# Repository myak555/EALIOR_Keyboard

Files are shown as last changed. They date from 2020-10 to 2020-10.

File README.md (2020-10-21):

# EALIOR Keyboard
8-key chorded mechanical keyboard for tablets

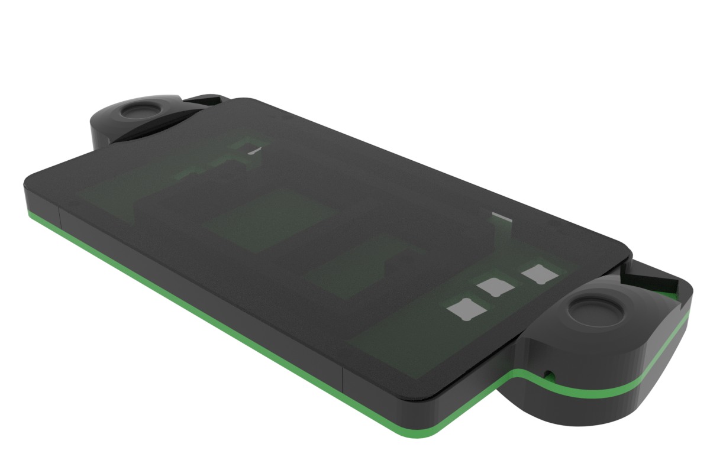
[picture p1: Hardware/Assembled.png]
Hardware


This is a much updated version of GKOS keyboard of Seppo Tiainen, 28-Mar-2010, and
GKOS keyboard of Pavel Travnik, 15-Sep-2019
  
Copyright (c) 2020 Mike Yakimov.

The name is derived from the first letters on the 6 chorded keys (if faced to the user):
  
Left_Thumb  E  I  Right_Thumb   
            A  O
            L  R

This is free software; you can redistribute it and/or modify it under the terms of the GNU Lesser General Public License as published by the Free Software Foundation; either version 3 of the License, or (at your option) any later version.

This software is distributed in the hope that it will be useful, but WITHOUT ANY WARRANTY; without even the implied warranty of MERCHANTABILITY or FITNESS FOR A PARTICULAR PURPOSE.  See the GNU Lesser General Public License for more details.

You should have received a copy of the GNU Lesser General Public License along with this library; if not, write to the Free Software Foundation, Inc., 51 Franklin St, Fifth Floor, Boston, MA  02110-1301  USA

 Inspired by prior work of:
 
* Seppo Tiainen (http://gkos.com/gkos/gkos-sixback.html)
* Pavel Travnik (https://hackaday.io/project/158377-mechanical-gkos-keyboard-for-phones-and-tablets) and the last but not least:
* Menny (https://github.com/AnySoftKeyboard/AnySoftKeyboard/commits?author=menny)

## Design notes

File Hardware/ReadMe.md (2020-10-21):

# Keyboard Hardware

The keyboard frame is composed of 4 laser-cut and 7 3D-printed parts. The actual sizes should be modified for the actual tablet. Instead of the laser, a CNC may be used (see NC files provided as an example). See Assembly.png.

1. Main keyboard frame - 3.4 mm plastic (Main_Frame.dxf)
1. Bottom cover - 3.4 mm plastic (Bottom_Cover.dxf)
1. Battery compartment cover - 3.4 mm plastic (Battery_Cover.dxf)
1. Top cover - 1.6 mm plastic (Top_Cover.dxf)
1. Upper left handle - PLA/ABS 3D print, 0.2 mm step(UpperLeft.stl)
1. Upper right handle - PLA/ABS 3D print, 0.2 mm step(UpperRight.stl)
1. Lower left handle - PLA/ABS 3D print, 0.2 mm step(BottomLeft.stl)
1. Lower right handle - PLA/ABS 3D print, 0.2 mm step(BottomRight.stl)
1. Horizontal extender, lower, - PLA/ABS 3D print, 0.2 mm step(MiddleBottom.stl)
1. Horizontal extender, upper, - PLA/ABS 3D print, 0.2 mm step(MiddleTop.stl)
1. Battery compartment - PLA/ABS 3D print, 0.2 mm step(BatteryBox3.stl)
1. Optional OTG pin holder - PLA/ABS 3D print, 0.2 mm step (OTG_Connector.stl)

# Bill of materials

See Schematics.png for assebly.

1. Sparkfun Arduino Micro Pro or equivalent - 1 ea
1. Micro-USB male connectors - 2 ea
1. Cherry mechanical switches or equivalents - 8 ea
1. 3 mm boxy LEDs (to fit Cherry LED openings) - 2 ea
1. Resistors 1.1K - 2 ea 
1. Power switch, 2 contact pairs  - 1 ea
1. Reset pushbutton - 1 ea
1. (Optional) perfboard - 1 ea
1. (Optional) pins, male 1x4 - 1 ea

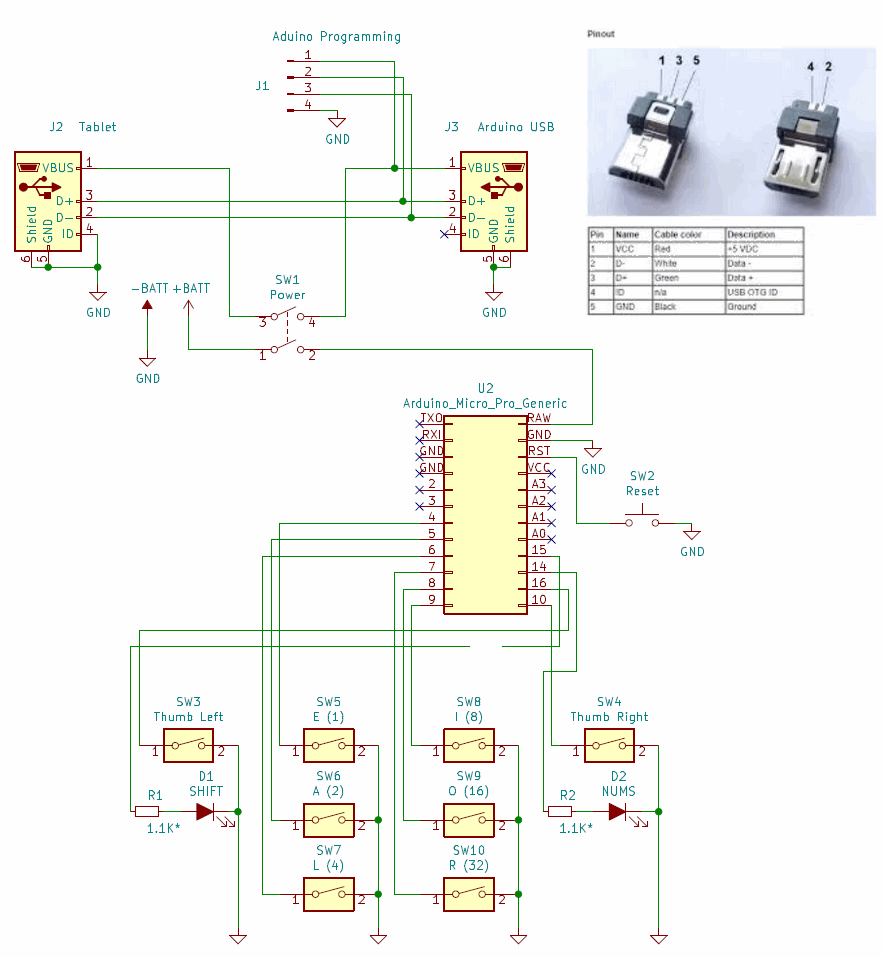
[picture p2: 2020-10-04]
Hardware/Schematics.png

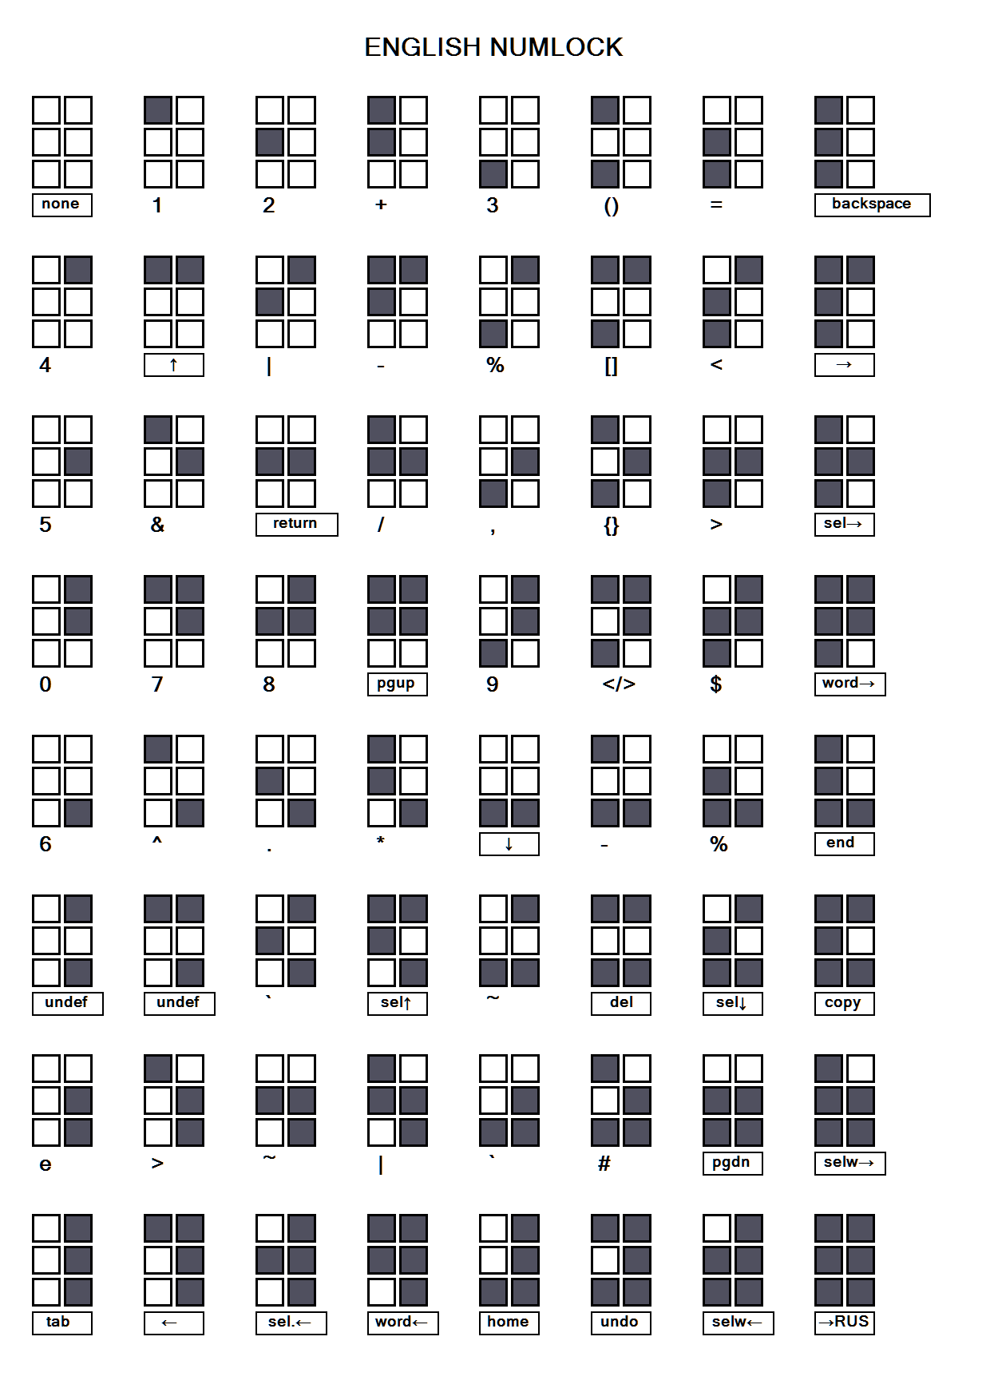
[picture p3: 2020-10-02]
Layout_Russian_Standard/ENGLISH_NUMLOCK_Layout_Russian_Standard.png

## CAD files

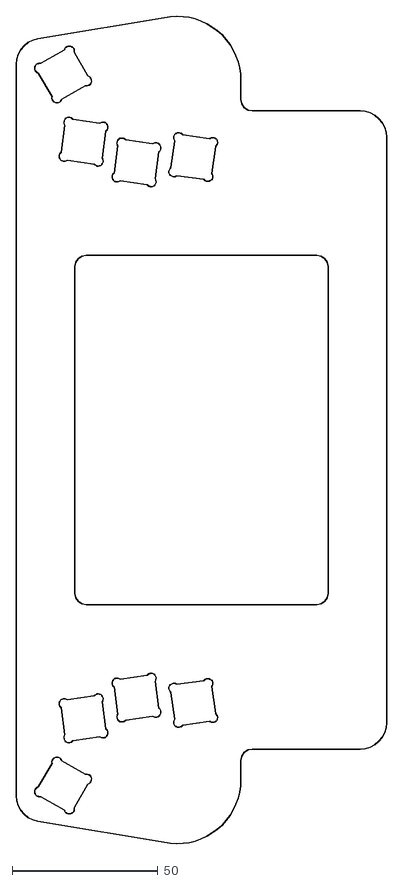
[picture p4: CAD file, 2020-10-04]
Hardware/Main_Frame.dxf
127.0 x 284.0

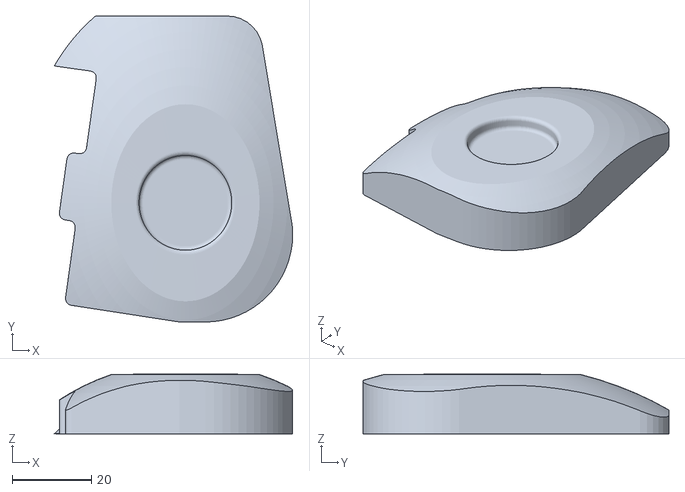
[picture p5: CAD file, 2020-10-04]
Hardware/BottomLeft.stl
60.0 x 77.0 x 15.0

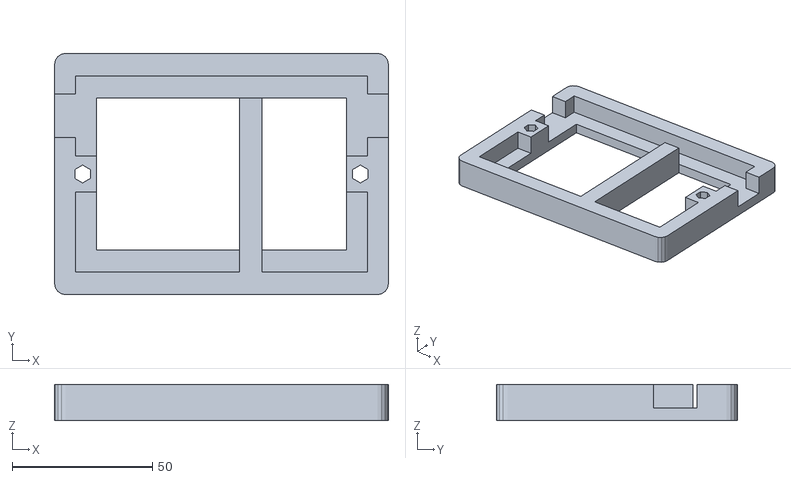
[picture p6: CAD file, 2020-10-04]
Hardware/BattryBox3.stl
119.0 x 86.0 x 13.0

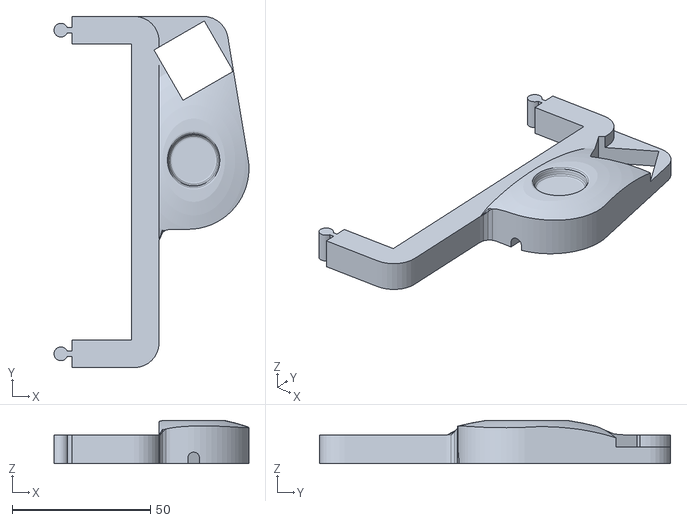
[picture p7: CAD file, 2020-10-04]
Hardware/UpperRight.stl
70.5 x 127.0 x 15.7

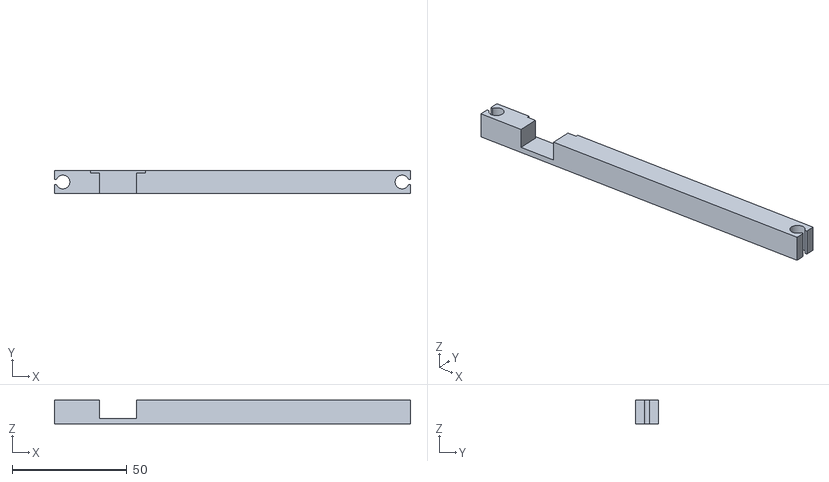
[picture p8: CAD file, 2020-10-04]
Hardware/MiddleTop.stl
155.4 x 10.0 x 10.3

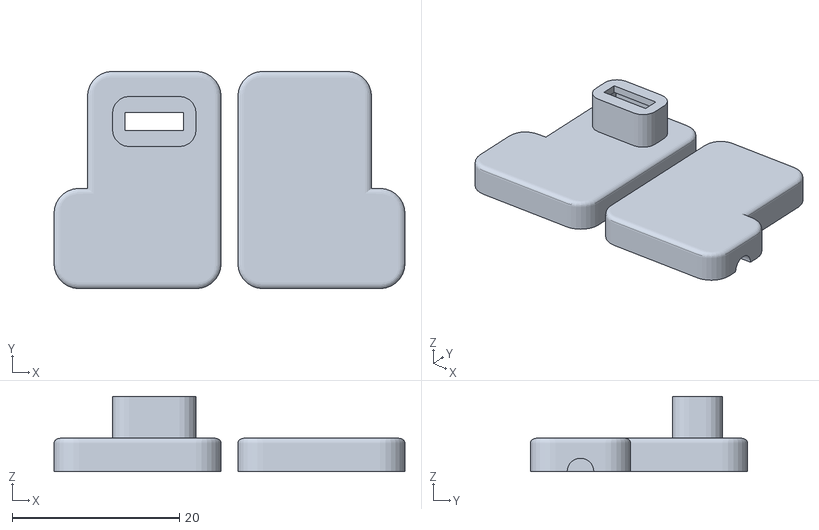
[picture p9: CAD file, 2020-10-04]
Hardware/OTG_Connector.stl
42.0 x 26.0 x 9.00

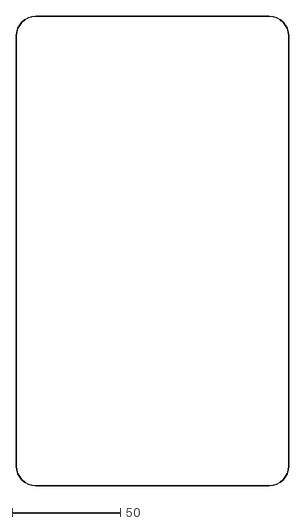
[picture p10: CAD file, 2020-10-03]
Hardware/Top_Cover.dxf
126.0 x 217.0

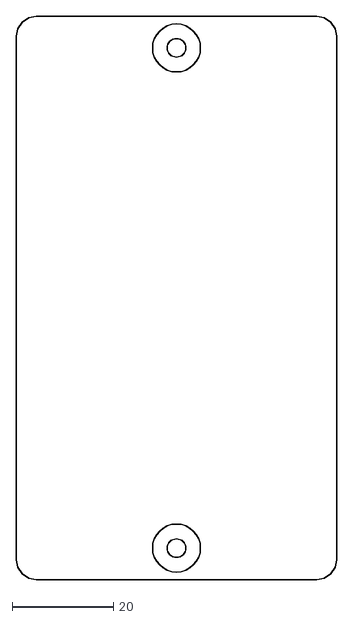
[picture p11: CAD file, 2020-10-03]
Hardware/Battery_Cover.dxf
63.5 x 111.6

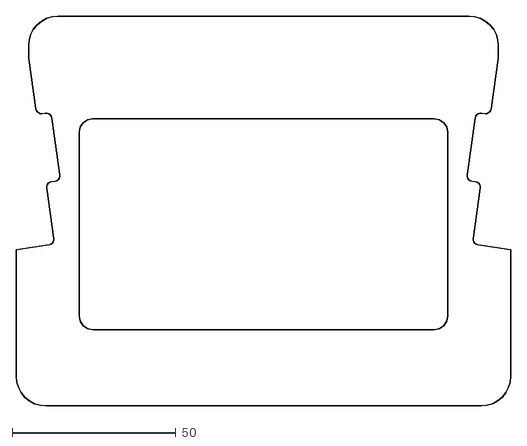
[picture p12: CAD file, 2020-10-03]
Hardware/Bottom_Cover.dxf
151.0 x 119.0

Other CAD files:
Hardware/BottomRight.stl
Hardware/UpperLeft.stl
Hardware/MiddleBottom.stl

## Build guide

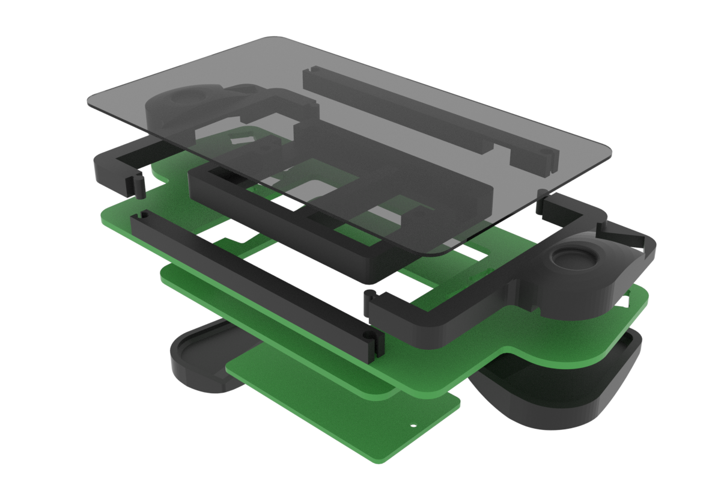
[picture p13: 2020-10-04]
Hardware/Assembly.png

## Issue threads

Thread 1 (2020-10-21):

With AnySoftKeyboard, shift is inconsistent with Russian layout

myak555, 2020-10-21:
Pressing Shift-Arrow on a hardware keyboard selects text. After the Shift is released and any button is pressed, AnySoftKeyboard believes that Shift is still pressed.

The issue is not observed in the the English layout.

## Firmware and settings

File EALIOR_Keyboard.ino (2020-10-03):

/*
  EALIOR (mark 4)
  This is a much updated version of GKOS keyboard of Seppo Tiainen, 28-Mar-2010, and
  GKOS keyboard of Pavel Travnik, 15-Sep-2019
  Copyright (c) 2020 Mike Yakimov.  All rights reserved.

  The name is derived from the first letters on the 6 chorded keys (if faced to the user):
  Left_Thumb  E  I  Right_Thumb   
              A  O
              L  R

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
 Inspired by work of: 
    Seppo Tiainen (http://gkos.com/gkos/gkos-sixback.html)
    Pavel Travnik (https://hackaday.io/project/158377-mechanical-gkos-keyboard-for-phones-and-tablets)
    and the last but not least: Menny (https://github.com/AnySoftKeyboard/AnySoftKeyboard/commits?author=menny)
*/

////////////////////////////////////////////////////////
//
// This code implementation is for (Chinese clone) Sparkfun Micro Pro ATMmega32U4 5V
//
// Pin assignment:
// Keys:
// Left_Thumb  E  I  Right_Thumb   
// Left_LED    A  O  Right_LED
//             L  R
//    16       5  8       10 
//    15       6  9       14
//             7  10
//
////////////////////////////////////////////////////////


#include "EALIOR_Decoder.hpp"

// Uncomment for serial debugging
//#define _DEBUG

static EALIOR_Hardware hardware;
static EALIOR_Decoder decoder;

//
// Setup code here, to run once:
//
void setup()
{
  #ifdef _DEBUG
  Serial.begin(9600);
  #endif
  hardware.init();
  decoder.init( &hardware);
}

//
// Runs continuously
//
void loop()
{
  if (hardware.readButtons())
    decoder.processKey();
  #ifdef _DEBUG
  delay(100);
  #else
  hardware.checkSleepRequired();
  #endif
}

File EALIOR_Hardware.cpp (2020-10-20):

/////////////////////////////////////////////////////////
//
//  EALIOR - 8-key chorded keyboard for tablets
//  Copyright (c) 2020 Mike Yakimov.  All rights reserved.
//  See main file for the license
//
//////////////////////////////////////////////////////////

#include <Arduino.h>
#include <Keyboard.h>
#include <LowPower.h>
#include "characters.h"
#include "EALIOR_Hardware.hpp"

// Uncomment to disable features while debugging
//#define _DISABLE_KEYBOARD
//#define _DISABLE_POWERSAVE
//#define _DEBUG

void EALIOR_Hardware::init(){
  pinMode(_LED_LEFT_, OUTPUT);
  pinMode(_LED_RIGHT_, OUTPUT);
  _writeLEDs( true, true);
  _kbdActive = false;
  for ( int i = 0; i < 8; i++){
    pinMode(_EALIORPins[i], INPUT_PULLUP);
    _kbdActive = _kbdActive || _readPinBool(i);
  }
  _kbdActive = !_kbdActive; // if any key is stuck, no runover
  if ( !_kbdActive) return;
  #ifndef _DISABLE_KEYBOARD
  Keyboard.begin();
  #endif
  _blinkLEDs();
  _setLEDs();
  _lastCommandReceived = millis();
}

//
// Reads the rear 6 buttons, processes them into the press codes
//
bool EALIOR_Hardware::readButtons(){
  if( !_kbdActive) return false;
  _readModeButtons();
  uint8_t button_weight = 1;
  int pin = 0;

  // Return empty immediately if 10 ms not elapsed
  _time = millis();
  if ((_time - _previousTime) < (10 + 64 * _autoRepeat)) return false;

  // Read buttons and form a code 
  _presentChord = 0;
  for( int i=0; i<6; i++){
    pin = _readPin( i);
    _presentChord += pin * button_weight;
    button_weight += button_weight; 
  }
  if(_presentChord) _lastCommandReceived = millis();
  #ifdef _DEBUG
  if(_presentChord)
    Serial.println( _presentChord, DEC);
  #endif

  // any buttons pressed
  if (_presentChord != 0){
    // Chord pressed long enough for autorepeat
    _autoCounter++;
    if (_autoCounter >= 100){
      _autoCounter = 99;
      _autoRepeat = 1;
    }

    // Chord pressed long enough to be first chord in Chordon
    //_firstCounter++;
    //if (_firstCounter > 25){
    //  _firstCounter = 25;
    //  if (_firstChord == 0) _firstChord = _presentChord;
    //}
  }

  // New key(s) pressed, expect a new character soon
  if (_presentChord > _previousChord){
    _gNew = true;
    _autoCounter = 0;
    _autoRepeat = 0;
    //_firstCounter = 0;
  }

  // key(s) relased
  if (_presentChord < _previousChord){
    _autoCounter = 0;
    _autoRepeat = 0;
    //EALIOR_firstCounter = 0;
    _gChord = _previousChord;  // the chord before the first release of key(s) is what we are after
    _previousChord = _presentChord;  
    _previousTime = _time;
    if (!_gNew) return false;
    _gNew = false; // next key releases will no more represent chords for characters
    return true; // a real chord entered!
  }

  // no buttons pressed
  //if (_presentChord == 0)
  //{
  //  _firstChord = 0; 
  //  _firstCounter = 0;
  //}
  _previousChord = _presentChord; // to be able to compare next time
  _previousTime = _time;

  if (!_autoRepeat) return false;
  _gChord = _previousChord;
  //_firstCounter = 0;
  //_firstChord = 0;
  return true;
}

void EALIOR_Hardware::setMode( uint8_t mode){
  if( shiftMode == mode) return;
  shiftMode = mode;
  _setLEDs();
}

void EALIOR_Hardware::_setLEDs(){
  uint8_t tmp = shiftMode % 5;
  const bool leftLED[5] = {false, true, true, false, true};
  const bool rightLED[5] = {false, false, false, true, true};
  _writeLEDs( leftLED[tmp], rightLED[tmp]);
}

void EALIOR_Hardware::kbdPress(char key){
  #ifndef _DISABLE_KEYBOARD
  kbdEnable();
  Keyboard.press( key);
  #endif
}

void EALIOR_Hardware::kbdWrite(char key){
  #ifndef _DISABLE_KEYBOARD
  kbdEnable();
  Keyboard.write( key);
  #endif
}

void EALIOR_Hardware::kbdPrint(String s){
  #ifndef _DISABLE_KEYBOARD
  kbdEnable();
  Keyboard.print( s);
  #endif
}

void EALIOR_Hardware::kbdRelease(char key){
  #ifndef _DISABLE_KEYBOARD
  kbdEnable();
  Keyboard.release( key);
  #endif
}

void EALIOR_Hardware::kbdReleaseAll(){
  #ifndef _DISABLE_KEYBOARD
  kbdEnable();
  Keyboard.releaseAll();
  #endif
}
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

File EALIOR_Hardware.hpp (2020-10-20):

/////////////////////////////////////////////////////////
//
//  EALIOR - 8-key chorded keyboard for tablets
//  Copyright (c) 2020 Mike Yakimov.  All rights reserved.
//  See main file for the license
//
//////////////////////////////////////////////////////////

#ifndef _EALIOR_HARDWARE_HPP
#define _EALIOR_HARDWARE_HPP

// if the user forgets to switch off the keyboard, go to sleep to prevent the battery drain
// 180 seconds is the default
#define SLEEP_DELAY (180000L)

// upon the keyboard connection, the system must recognize it
// tested on PC 1000 ms Ok
#define KBD_WAKEUP_TIMEOUT 1000

// double-pressing shift results in release capslock
#define DOUBLE_PRESS_TIMEOUT 300

// controls the wait upon a buttion press, e.g. after pressing Control or Shift
#define BUTTON_PRESS_TIMEOUT 30

//
// Pin assignment
//
#define _EALIOR_KEY_0_      4
#define _EALIOR_KEY_1_      5
#define _EALIOR_KEY_2_      6
#define _EALIOR_KEY_3_      7
#define _EALIOR_KEY_4_      8
#define _EALIOR_KEY_5_      9
#define _THUMB_KEY_LEFT_   16
#define _THUMB_KEY_RIGHT_  10
#define _LED_LEFT_         15
#define _LED_RIGHT_        14

class EALIOR_Hardware{
  public:
    void init();
    bool readButtons();
    void setMode( uint8_t mode);
    inline uint16_t getFullCode(){
        return 10*_gChord + shiftMode;};

    void kbdPress(char key);
    void kbdWrite(char key);
    void kbdPrint(String s);
    void kbdRelease(char key);
    void kbdReleaseAll();
    inline void kbdHold(){ delay( BUTTON_PRESS_TIMEOUT);};
    void kbdDisable( bool force_sleep=false);
    void kbdEnable();
    void checkSleepRequired();
  private:
    int8_t _EALIORPins[8] = {_EALIOR_KEY_0_, _EALIOR_KEY_1_, _EALIOR_KEY_2_,
                             _EALIOR_KEY_3_, _EALIOR_KEY_4_, _EALIOR_KEY_5_,
                             _THUMB_KEY_LEFT_, _THUMB_KEY_RIGHT_};
    long _lastCommandReceived = 0L;   // Controls keyboard sleep
    bool _leftPressed = false;        // previous value of the left (front) mode button
    bool _rightPressed = false;       // previous value of the right (front) mode button
    long _time = 0;                   // button press time
    long _previousTime = 0;
    long _autoRepeat = 0;             // Repeat the character if chord pressed long enough (0 or 1)
    int  _presentChord = 0;           // The chord of the keypad at present
    int  _previousChord = 0;          // To compare chord change
    int  _autoCounter = 0;            // Typematic delay counter (n x 10 ms)
    //int   EALIOR_firstChord = 0;    // First chord of a Chordon, if any
    //int   EALIOR_firstCounter = 0;  // Count to detect a separate first chord in a Chordon
    bool  _gNew = false;              // a new character is expected soon because new keys were pressed
    bool _kbdActive = false;                       // prevents keyboard going bananas
    bool _kbdSleeping = false;                     // prevents keyboard going bananas
    uint16_t  _gChord = 0;                         // EALIOR final chord value (0...63) for the character
    uint8_t  shiftMode = _SHIFTMODE_LAT_NORMAL;    // keyboard mode

    void _readModeButtons();
    void _readModeRight( bool);
    void _readModeLeft( bool);
    void _blinkLEDs();
    void _setLEDs();
    inline void _writeLEDs( bool left, bool right){
        digitalWrite(_LED_LEFT_, left);
        digitalWrite(_LED_RIGHT_, right);};
    inline int8_t _readPin( int i){
        return (digitalRead( _EALIORPins[i]) == LOW)? 1: 0;};
    inline int8_t _readPinBool( int i){
        return digitalRead( _EALIORPins[i]) == LOW;};
};

#endif // _EALIOR_HARDWARE_HPP

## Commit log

2020-10-03 Added schematics
2020-10-04 Updated schematics
    [OTG_Connector.stl]
